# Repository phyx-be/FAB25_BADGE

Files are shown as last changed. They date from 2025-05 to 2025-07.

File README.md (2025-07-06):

# FAB25_BADGE
We've been asked by our friends over at [FabLab Leuven](https://fablab-leuven.be/) to design a solder kit for the [FAB25](https://fab25.fabevent.org/) conference in Czechia.

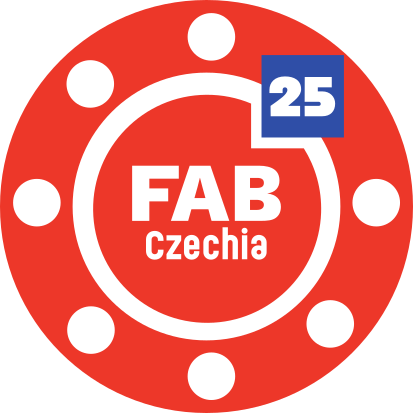
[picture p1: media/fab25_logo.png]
FAB25 logo


## Design
In order to make the kit a bit more advanced we opted to use a [555 timer](https://www.ti.com/product/TLC555) IC to generator a clock signal for a [4017 counter](https://www.ti.com/product/CD4017B) IC. This will result in LEDs lighting up one by one around the logo. A slide switch on the back allows users to disable the light show to save power. 

## Chip marking
Since the ICs would cover op parts of the identifying marks of the logo, we opted to mark the ICs with "25" and "Czechia". This was done by laser engraving the ICs and filling those engravings with paint.

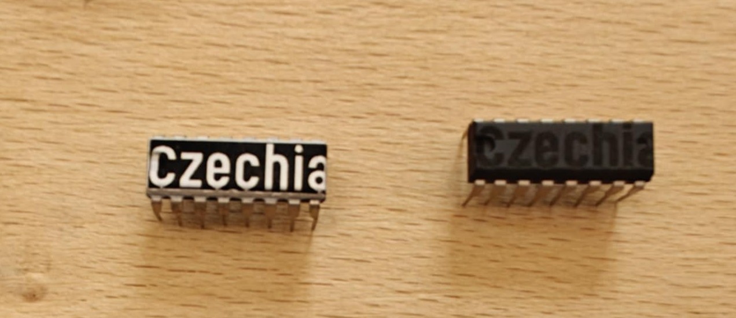
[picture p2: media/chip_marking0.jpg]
chip engraving

Sample chip engraving and painting.

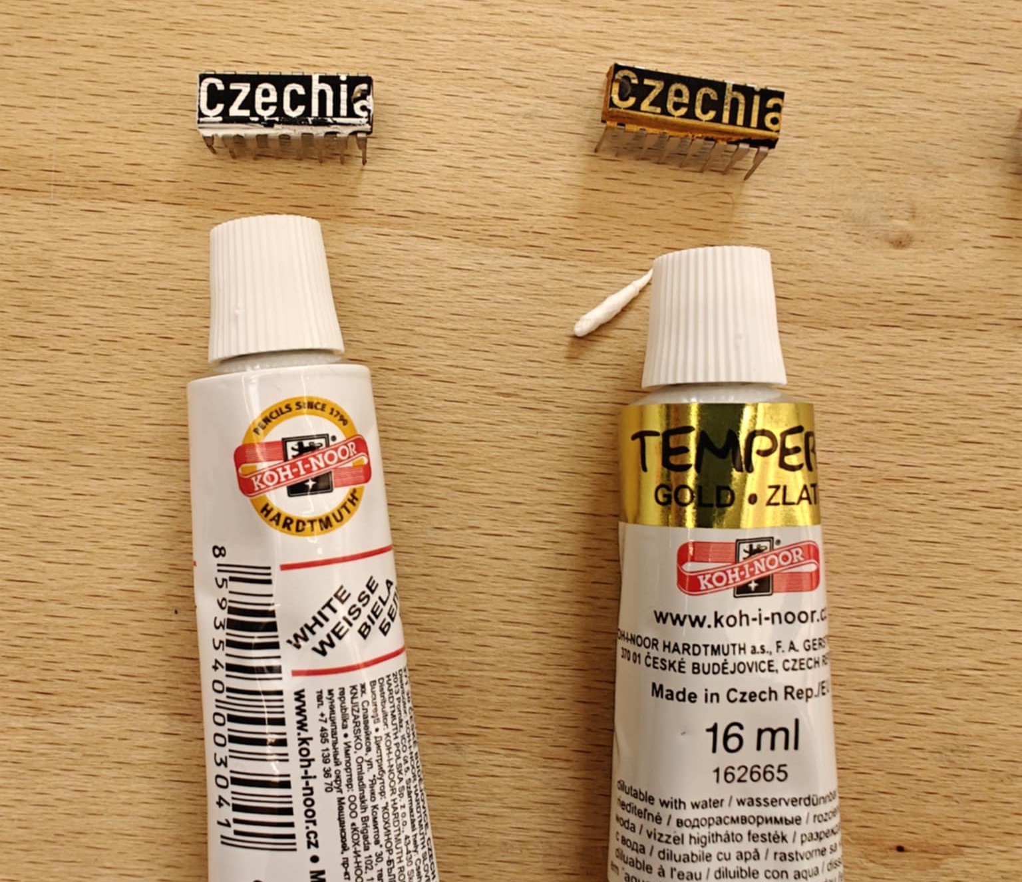
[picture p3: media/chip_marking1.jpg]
chip painting with white and gold paint

First test with gold and white paint.

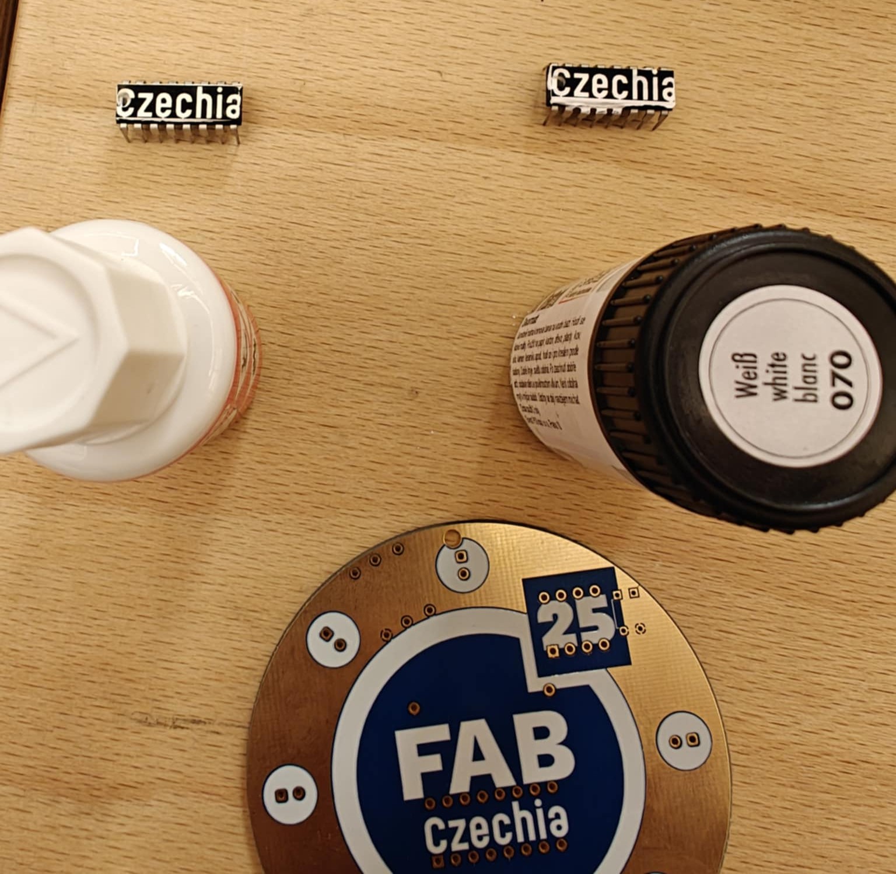
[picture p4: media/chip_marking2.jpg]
chip painting with alternative white paints

Testing with different white paints.

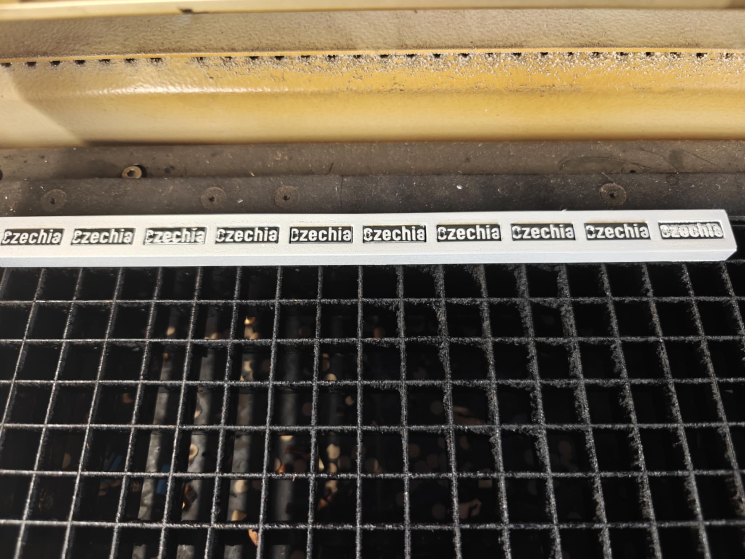
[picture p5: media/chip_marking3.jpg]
mass chip engraving and painting with a rig in a laser cutter

Mass engraving of the ICs in the laser cutter with a custom jig to speed up the process (a total of 2000 chips had to be marked).

## REV 00
Initial version of the design based on the [FAB25](https://fab25.fabevent.org/) logo.

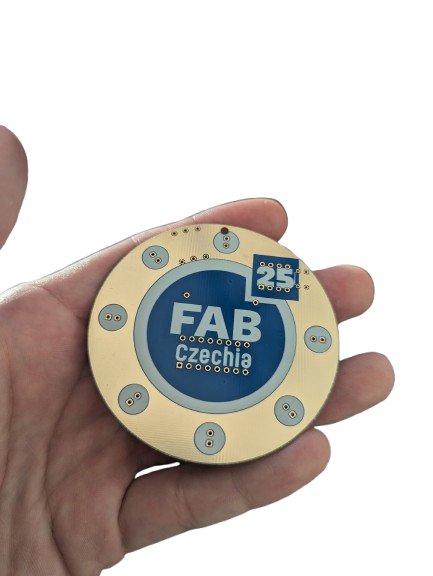
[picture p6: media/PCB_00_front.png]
Bare PCB front

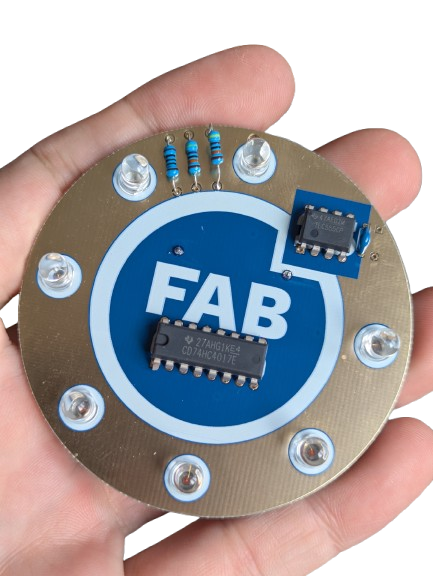
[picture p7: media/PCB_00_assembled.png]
Assembled PCB front


## REV 01
Revision 01 is the mass production version of the kit. Besides an update to the graphical design and adding the sponsor logo, we als removed the unnecessary capacitor, added the switch and increased the animation speed by reducing the 470kΩ resistors to 100kΩ. 
R1 and R2 are 100kΩ, C1 is 1µF, the animation speed can be calculated using the following formula: f=1.44/[(R1+2*R2)C1]=4,8Hz

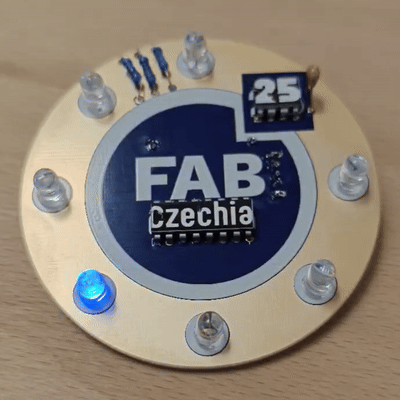
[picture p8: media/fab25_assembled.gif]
Animated FAB25 kit


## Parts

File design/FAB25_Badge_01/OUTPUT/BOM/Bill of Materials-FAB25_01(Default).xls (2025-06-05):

Bill of Materials |  |  | FAB25 Logo
Project: |  | FAB25_01.PrjPcb
Revision: |  | 01
Variant: |  | Default
Creation Date: | 04/06/2025 | 11:08
Print Date: | 2025-06-04 | 11:08:26
Footprint | Comment | LibRef | Designator | Value | Description | Supplier 1 | Supplier Part Number 1 | Supplier 2 | Supplier Part Number 2 | Supplier 3 | Supplier Part Number 3 | Quantity
BAT_CR2032_China | CR2032 Battery Holder | BAT 20mm Coin Cell Holder Generic | BAT1 | CR2032 | BAT 20mm Coin Cell Holder Generic | LCSC | C5239862 | LCSC | C70376 |  |  | 1
C_5.08mm |  | CAP 1uF 50V X7R 5.08mm | C1 | 1uF 50V X7R | CAP 1uF 50V X7R 5.08mm | LCSC | C263186 | LCSC | C5632434 |  |  | 1
LED_5MM_RD | Default 5mm Red LED | LED Red 5mm | D1, D2, D3, D4, D5, D6, D7 |  | LED Red 5mm | Farnell | 2335725 | LCSC | C2895484 |  |  | 7
RES_10mm |  | RES 100k 1/4W | R1, R2 | 100k | RES 100k 1/4W | LCSC | C2903268 | LCSC | C2843019 | Generic | 100k 1/4W 1% TH 10mm | 2
RES_10mm |  | RES 100R 1/4W | R3 | 100R | RES 100R 1/4W | LCSC | C57438 | LCSC | C2903231 | Generic | 100R 1/4W 1% TH 10mm | 1
SS-12D07 | mini Switch 1 pole double throw | SW 1P2T micro SS-12D07 | SW1 | SS-12D07 | SW 1P2T micro SS-12D07 | LCSC | C22435632 | LCSC | C22435634 | LCSC | C22435633 | 1
DIP_N_8 | General purpose Timer IC 555 3V DIP 8 | 555 Timer DIP8 3V | U1 | 555 | 555 Timer DIP8 3V | LCSC | C725329 | LCSC | C5274684 |  |  | 1
DIP_N_16 | CD74HC4017 High-Speed CMOS Logic Decade Counter/Divider with 10 Decoded Outputs | COUNT CD74HC4017E DIP16 | U2 | CD74HC4017E | COUNT CD74HC4017E DIP16 | Ti | CD74HC4017E | LCSC | C354048 | Farnell | 3119779 | 1
 |  |  |  |  |  |  |  |  |  |  |  | 15
Approved |  | Notes

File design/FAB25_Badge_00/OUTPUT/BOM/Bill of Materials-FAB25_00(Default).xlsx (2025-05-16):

Comment | Description | Designator | Footprint | LibRef | Quantity | Supplier 1 | Supplier Part Number 1 | Value | Supplier 2 | Supplier Part Number 2 | Supplier 3 | Supplier Part Number 3
CR2032 Battery Holder | BAT 20mm Coin Cell Holder Generic | BAT1 | BAT_CR2032_China | BAT 20mm Coin Cell Holder Generic | 1 | LCSC | C5239862 | CR2032 | LCSC | C70376
 | CAP 1uF 50V X7R 5.08mm | C1 | C_5.08mm | CAP 1uF 50V X7R 5.08mm | 1 | LCSC | C263186 | 1uF 50V X7R | LCSC | C5632434
Default 5mm Red LED | LED Red 5mm | D1, D2, D3, D4, D5, D6, D7 | LED_5MM_RD | LED Red 5mm | 7 | Farnell | 2335725 |  | LCSC | C2895484
 | RES 470k 1/4W | R1, R2 | RES_10mm | RES 470k 1/4W | 2 | LCSC | C119381 | 470k | LCSC | C2903284 | Generic | 470k 1/4W 1% TH 10mm
 | RES 100R 1/4W | R3 | RES_10mm | RES 100R 1/4W | 1 | LCSC | C57438 | 100R | LCSC | C2903231 | Generic | 100R 1/4W 1% TH 10mm
General purpose Timer IC 555 3V DIP 8 | 555 Timer DIP8 3V | U1 | DIP_N_8 | 555 Timer DIP8 3V | 1 | LCSC | C725329 | 555 | LCSC | C5274684
CD74HC4017 High-Speed CMOS Logic Decade Counter/Divider with 10 Decoded Outputs | COUNT CD74HC4017E DIP16 | U2 | DIP_N_16 | COUNT CD74HC4017E DIP16 | 1 | Ti | CD74HC4017E | CD74HC4017E | LCSC | C354048 | Farnell | 3119779

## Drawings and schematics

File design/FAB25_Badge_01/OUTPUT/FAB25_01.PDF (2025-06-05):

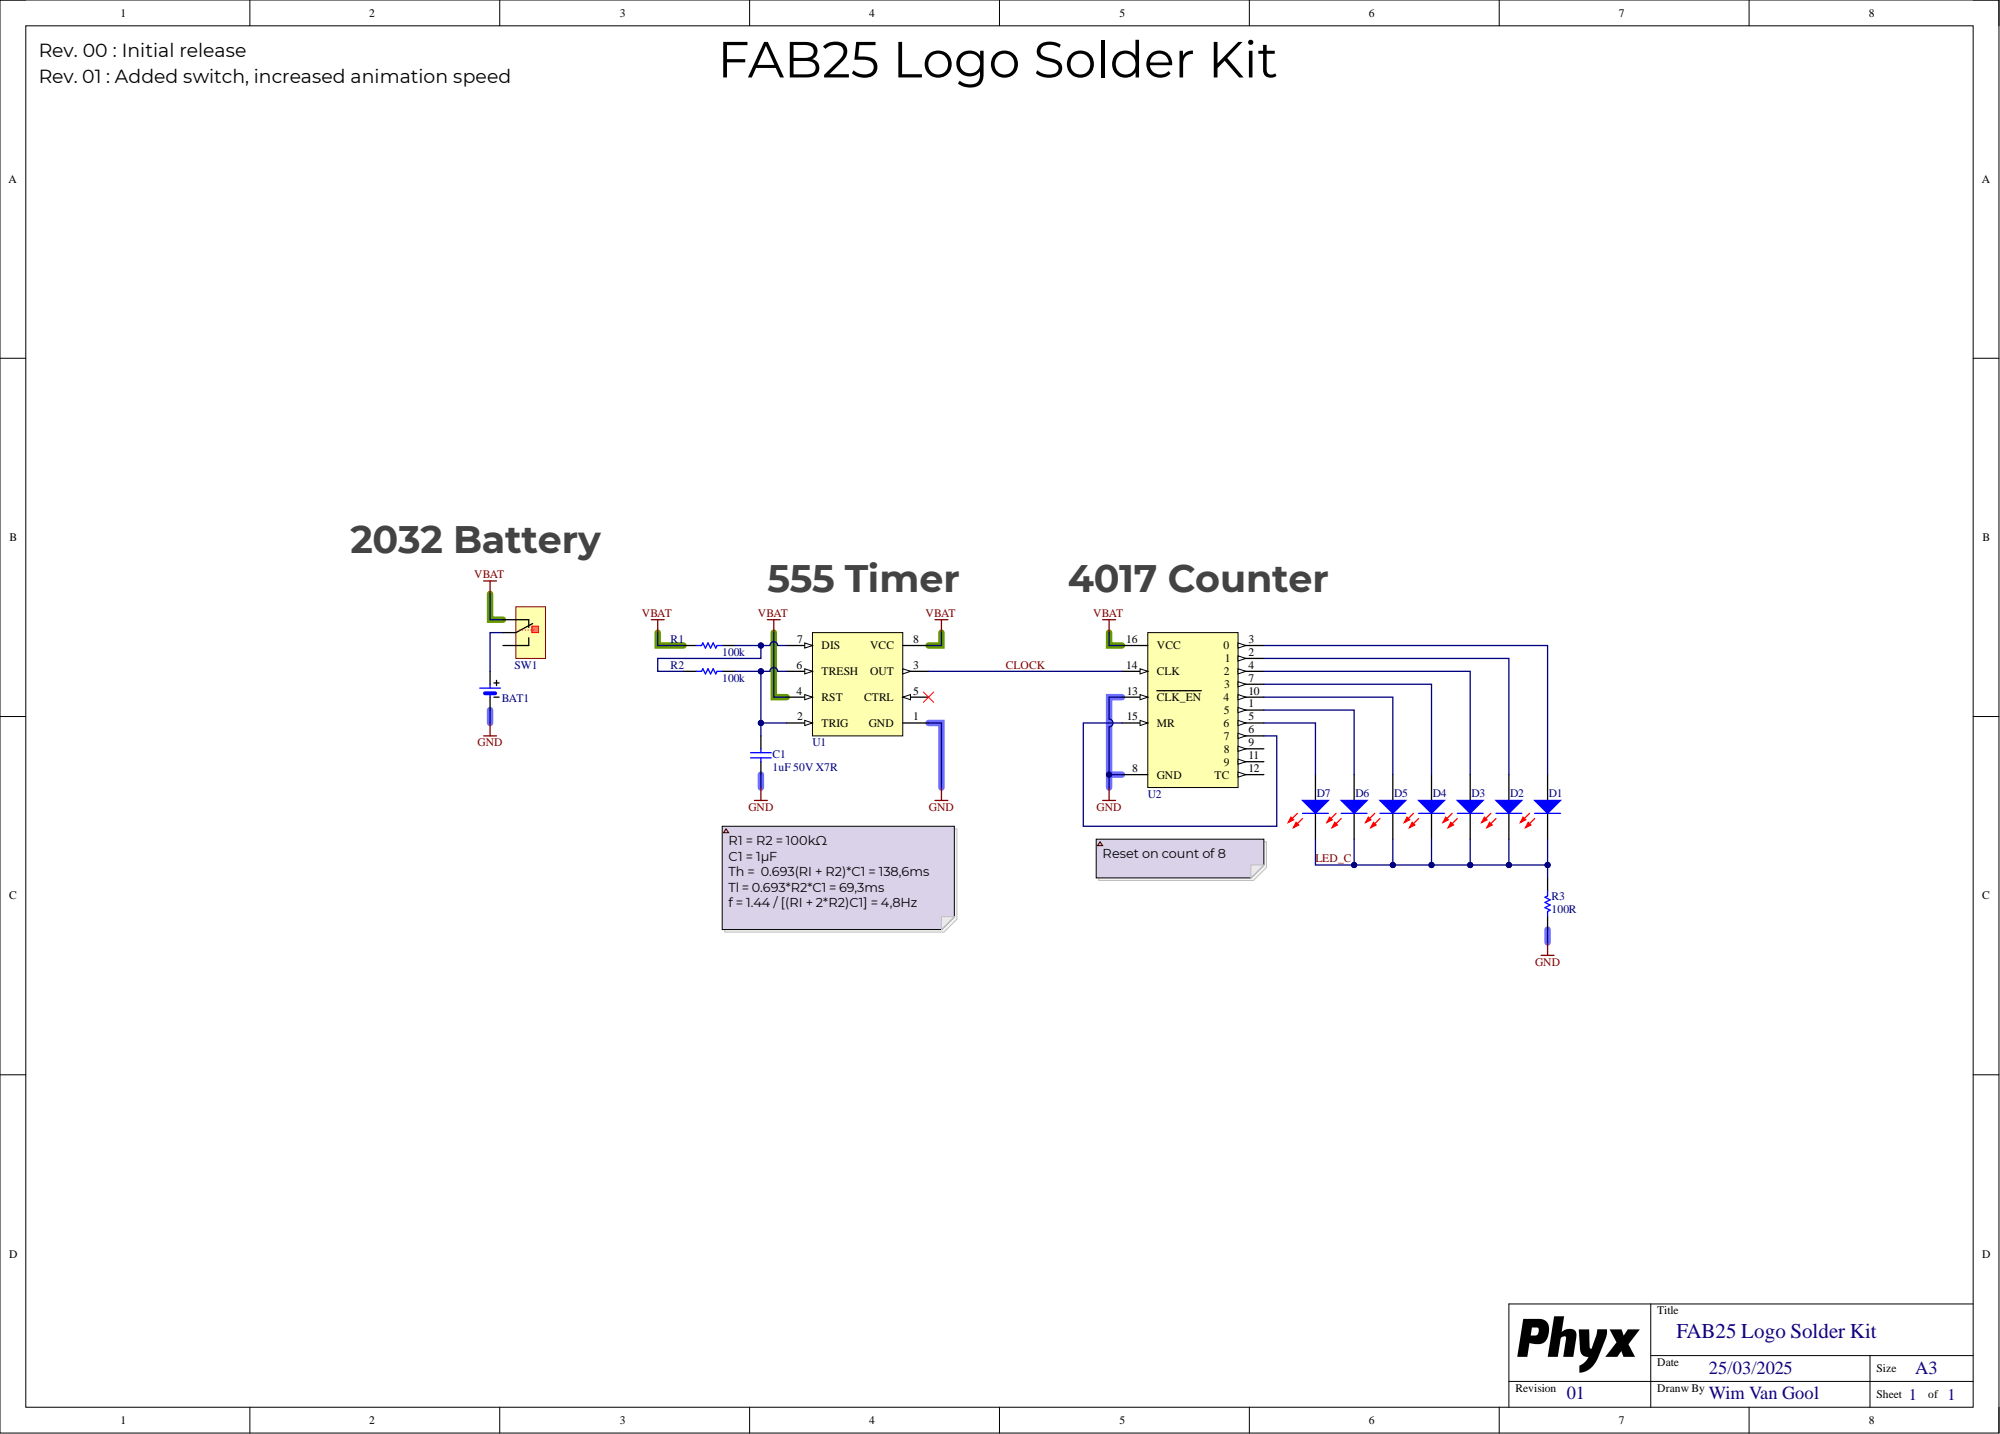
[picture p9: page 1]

FAB25 Logo Solder Kit Rev. 00 : Initial release
Rev. 01 :

Reset on count of

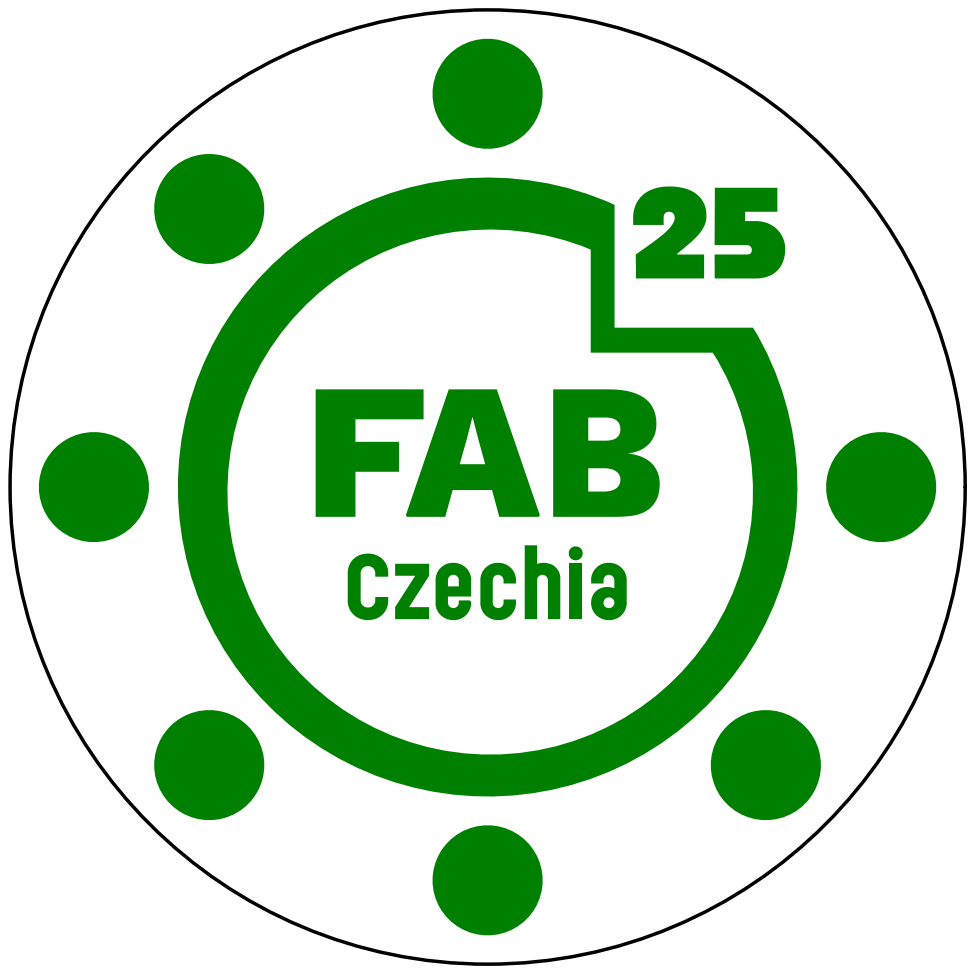
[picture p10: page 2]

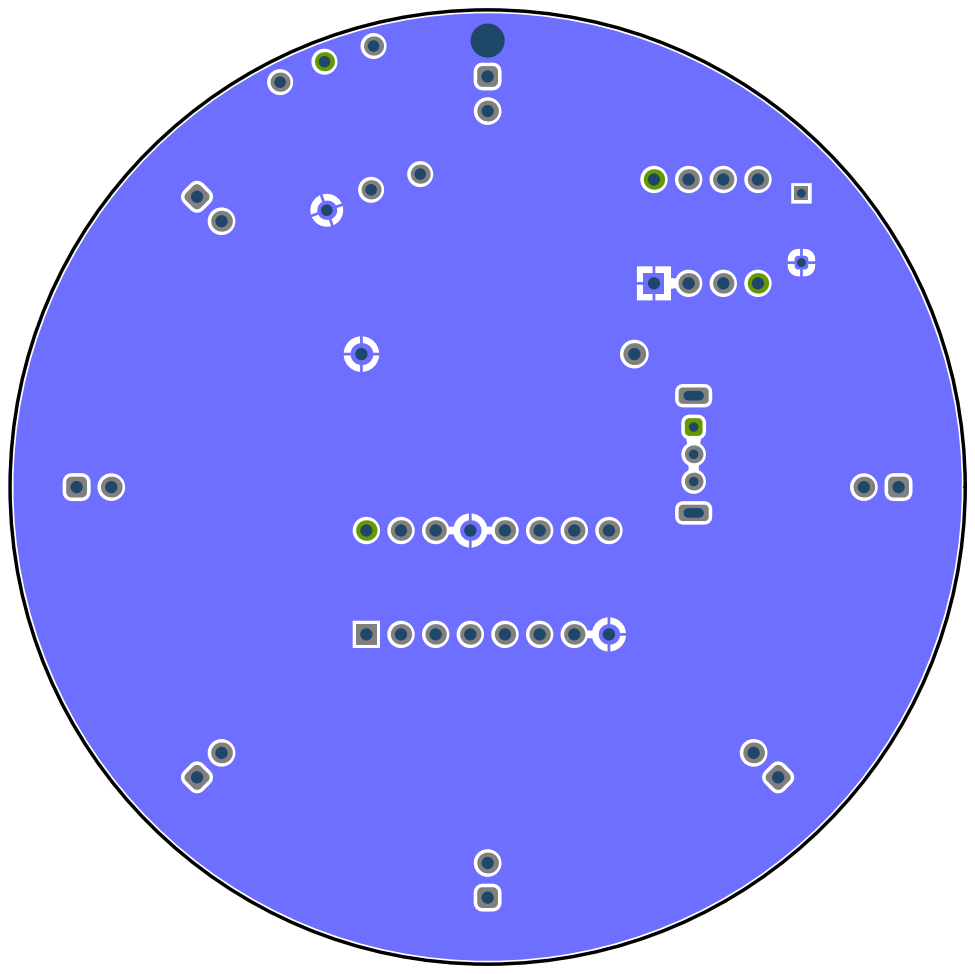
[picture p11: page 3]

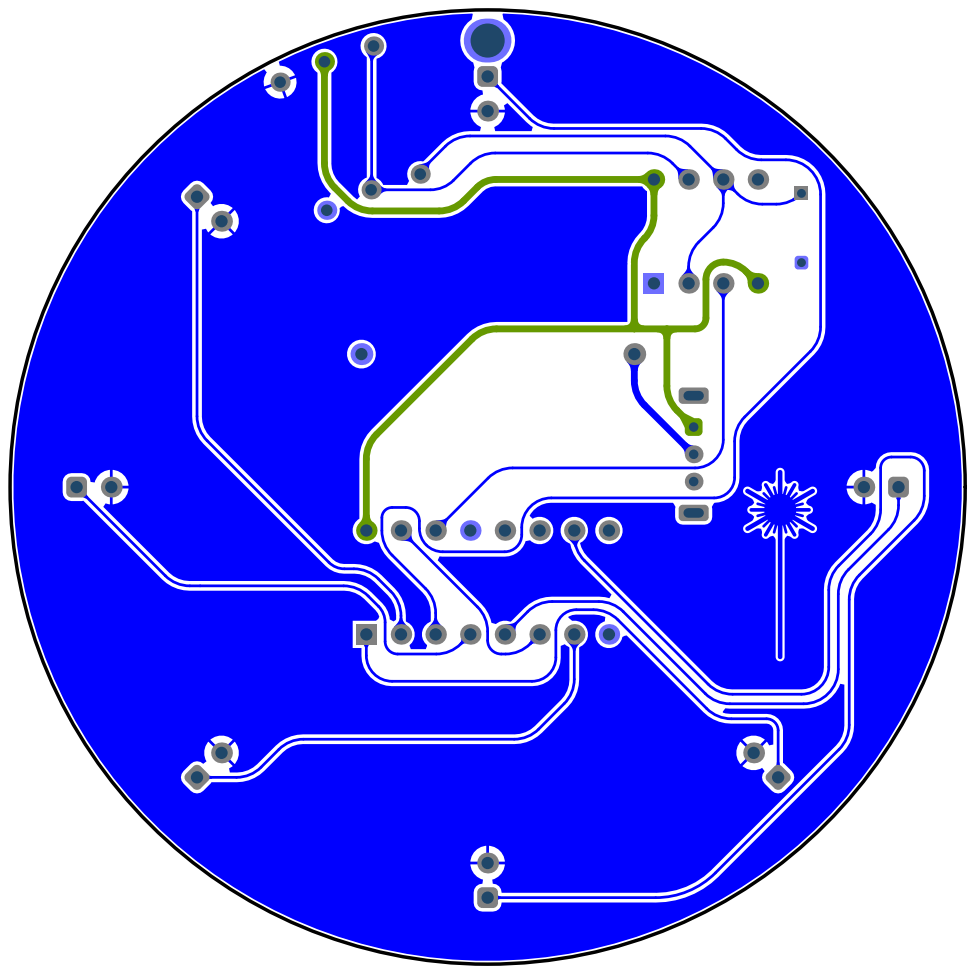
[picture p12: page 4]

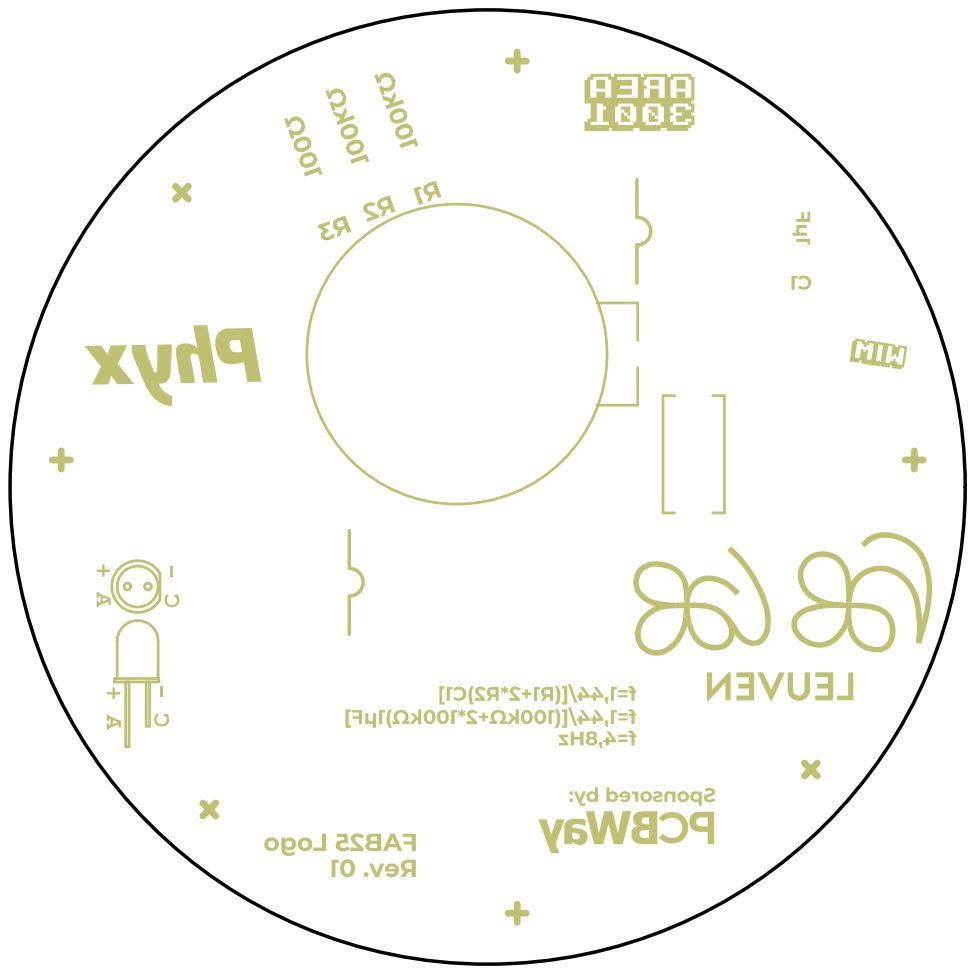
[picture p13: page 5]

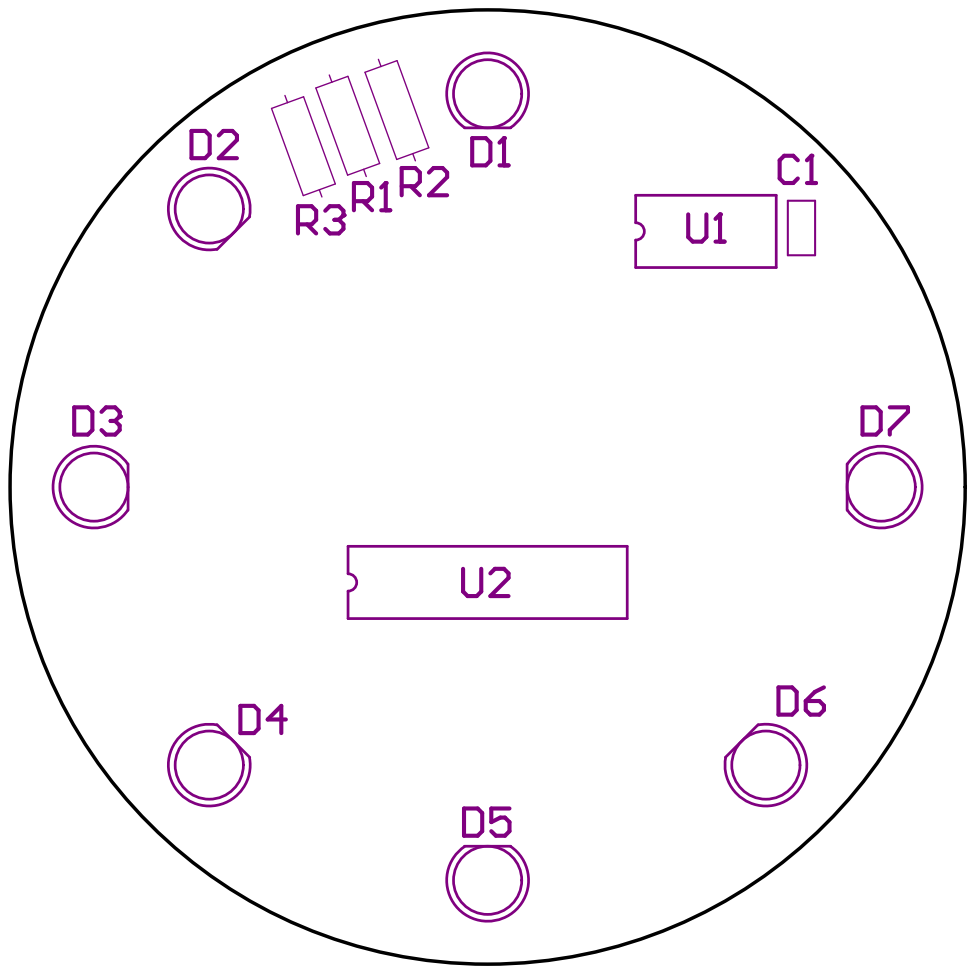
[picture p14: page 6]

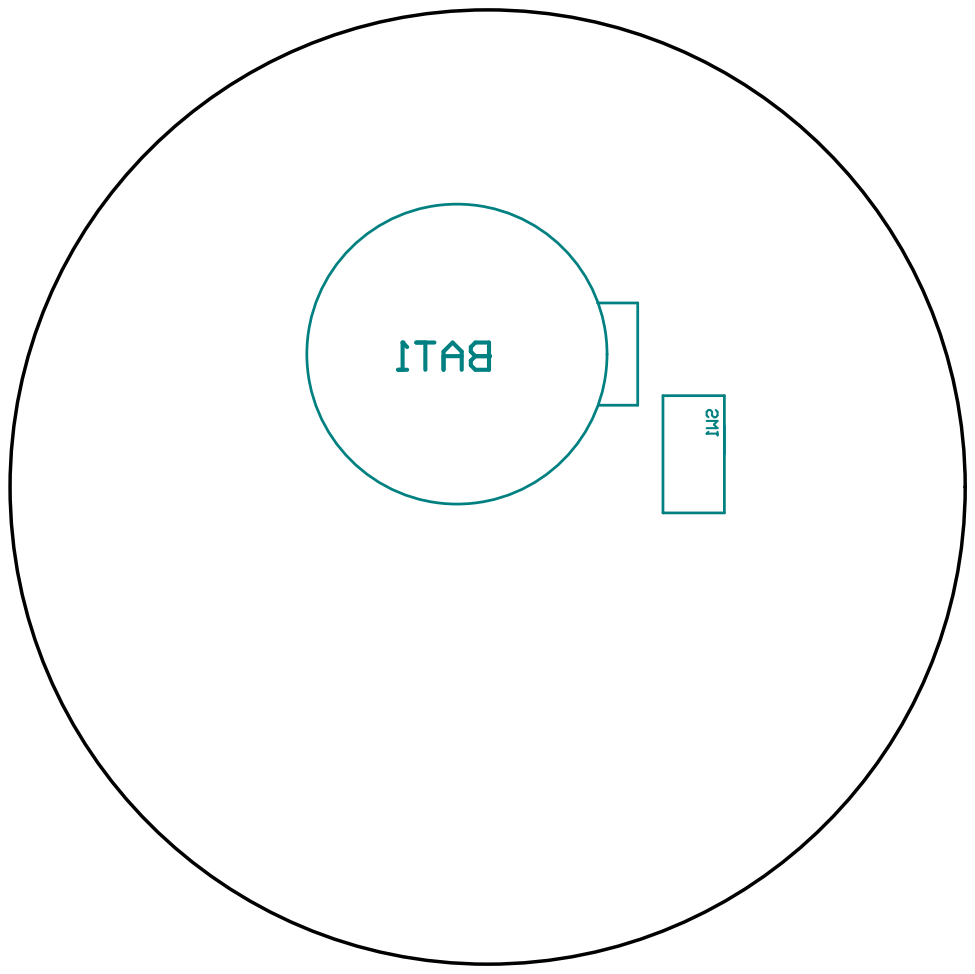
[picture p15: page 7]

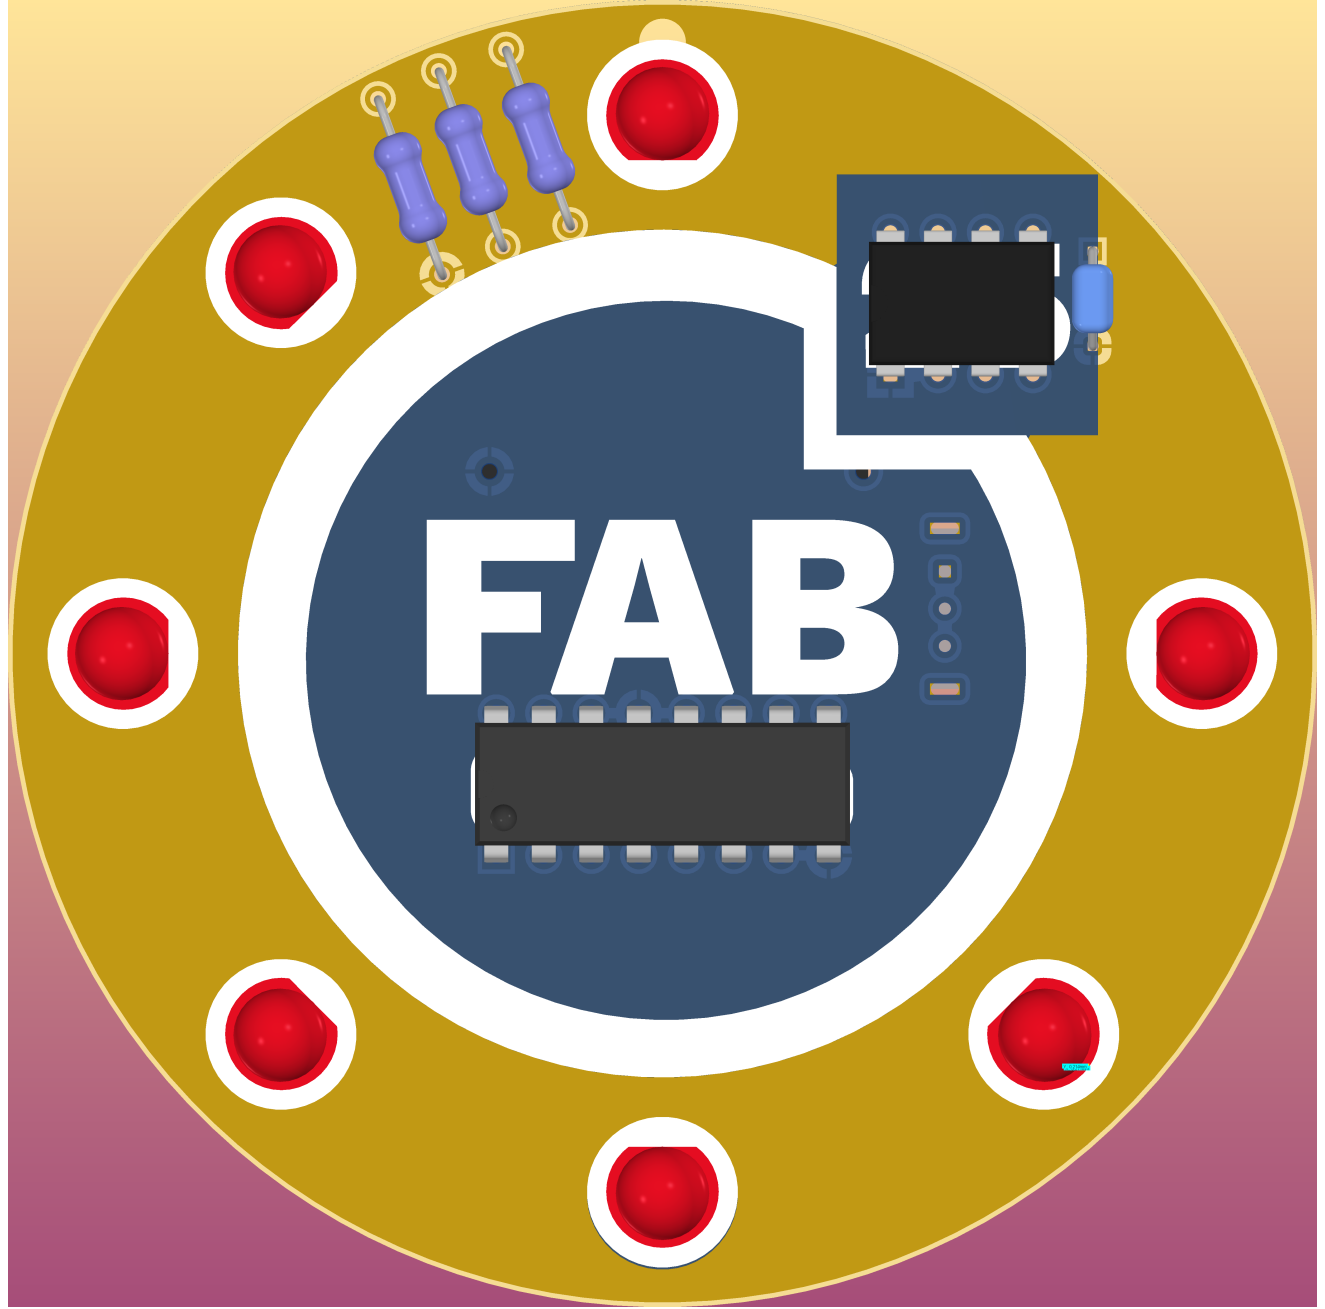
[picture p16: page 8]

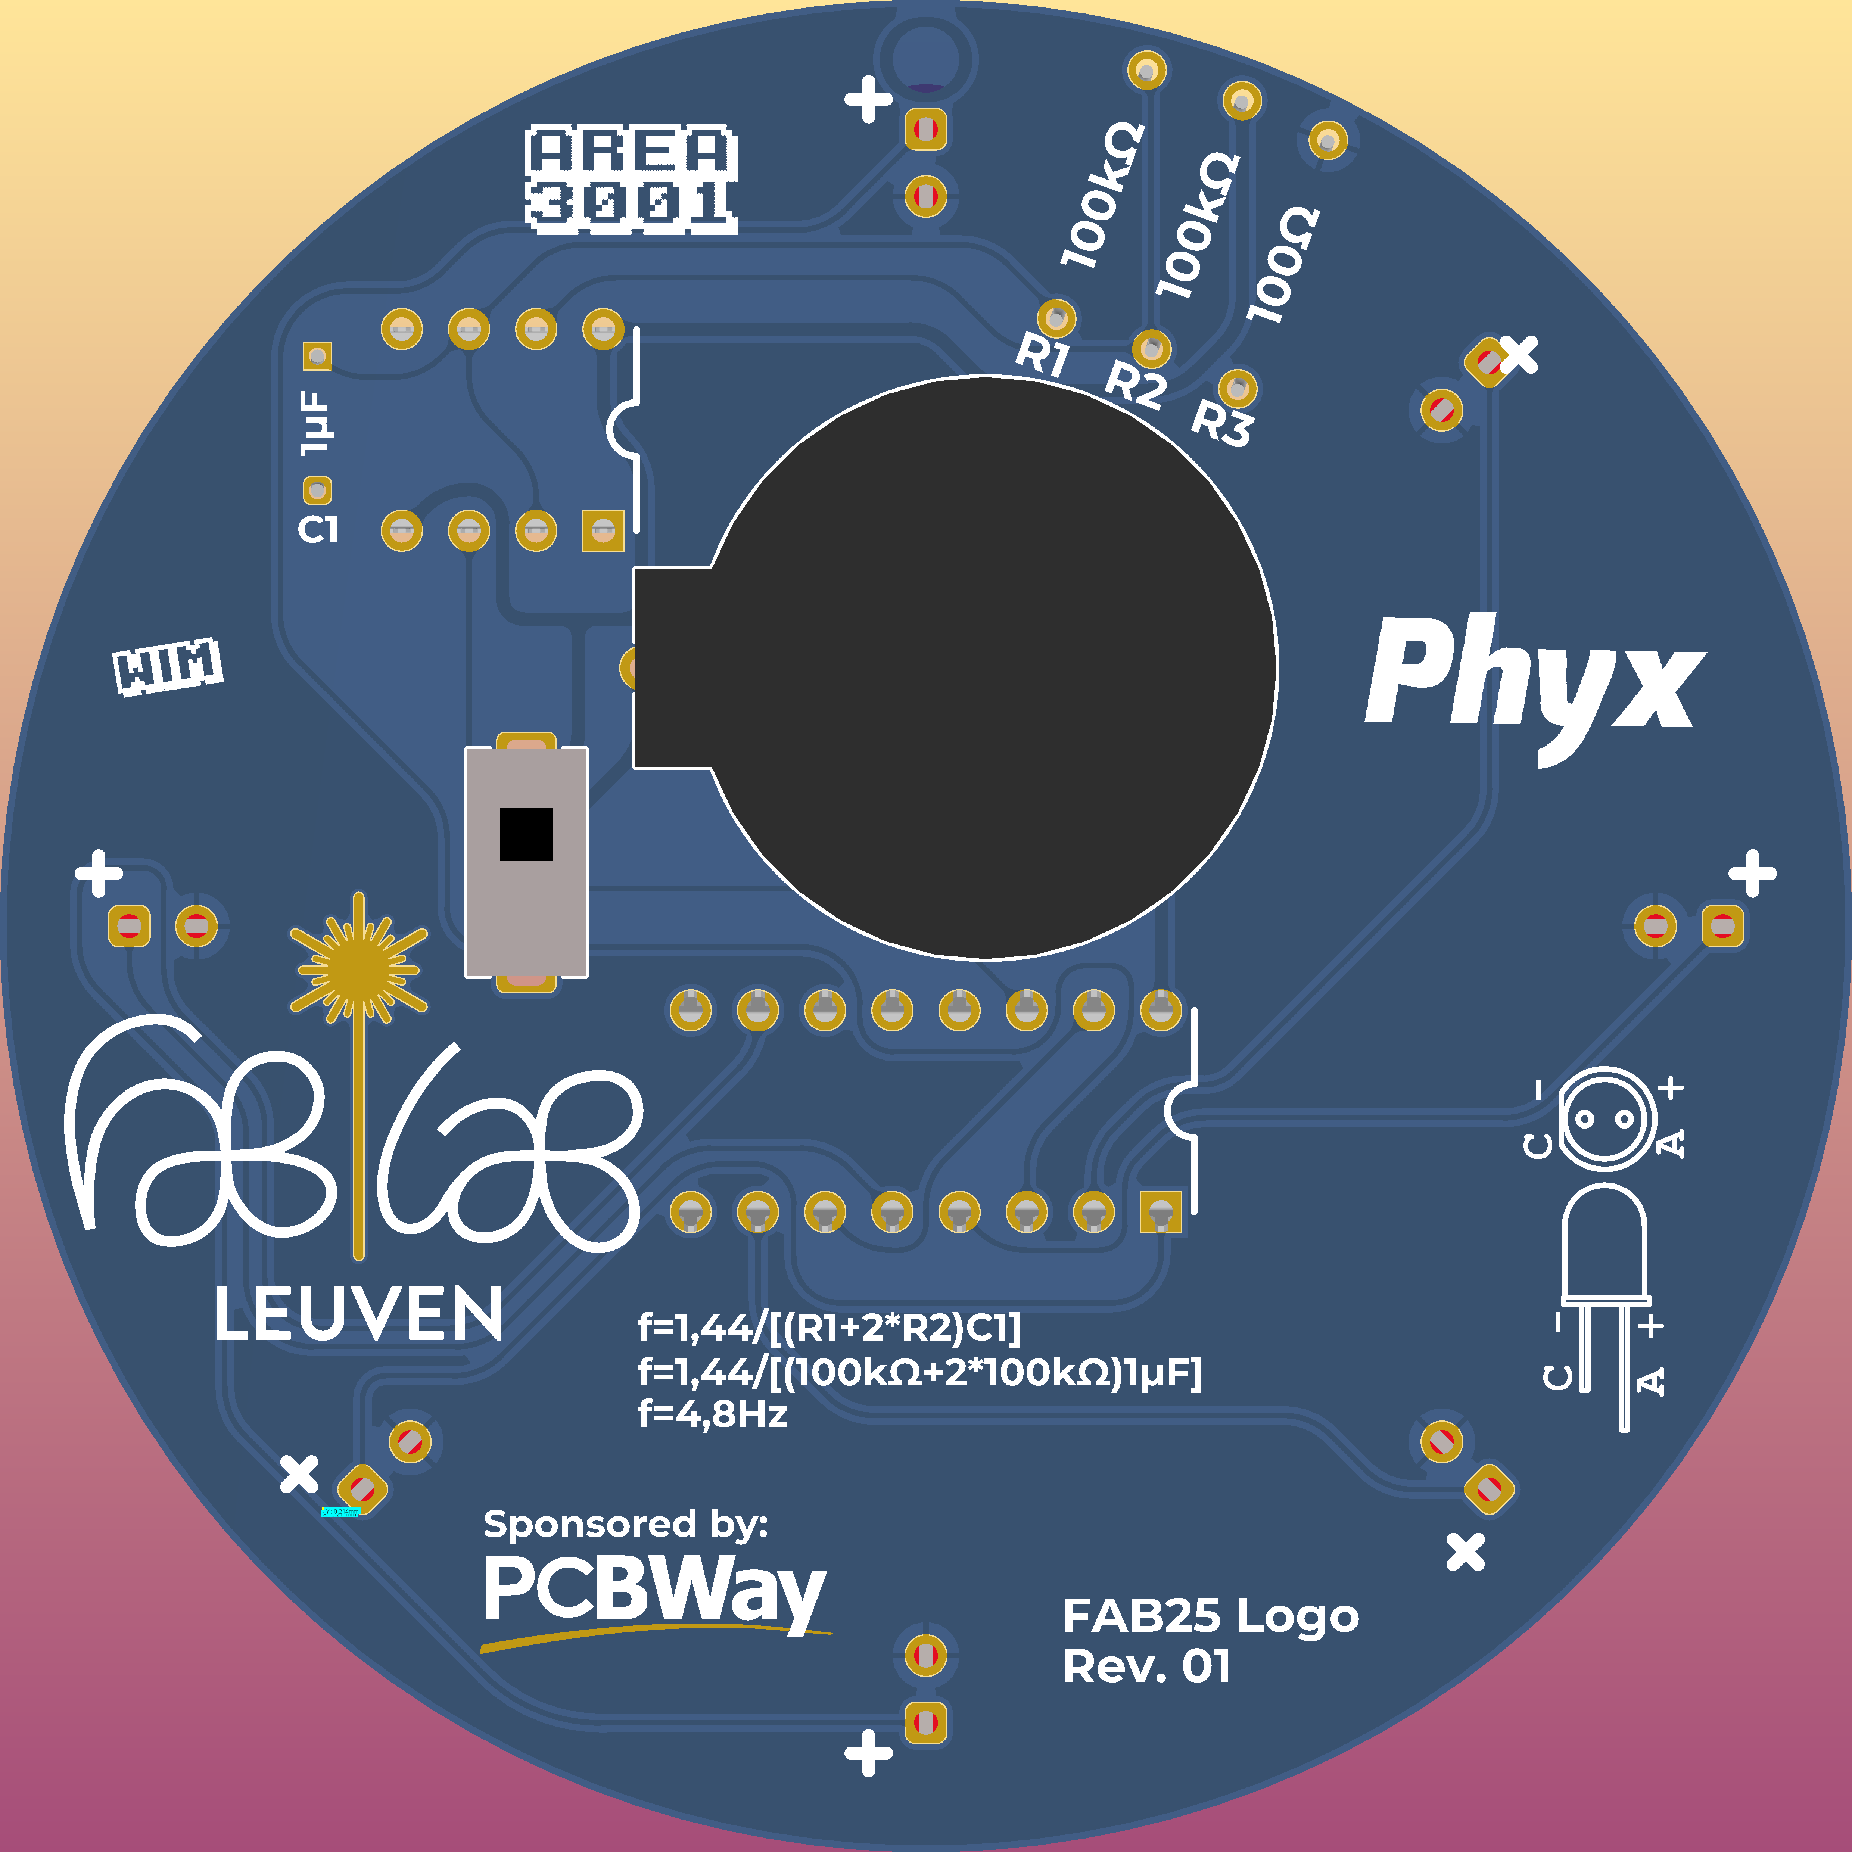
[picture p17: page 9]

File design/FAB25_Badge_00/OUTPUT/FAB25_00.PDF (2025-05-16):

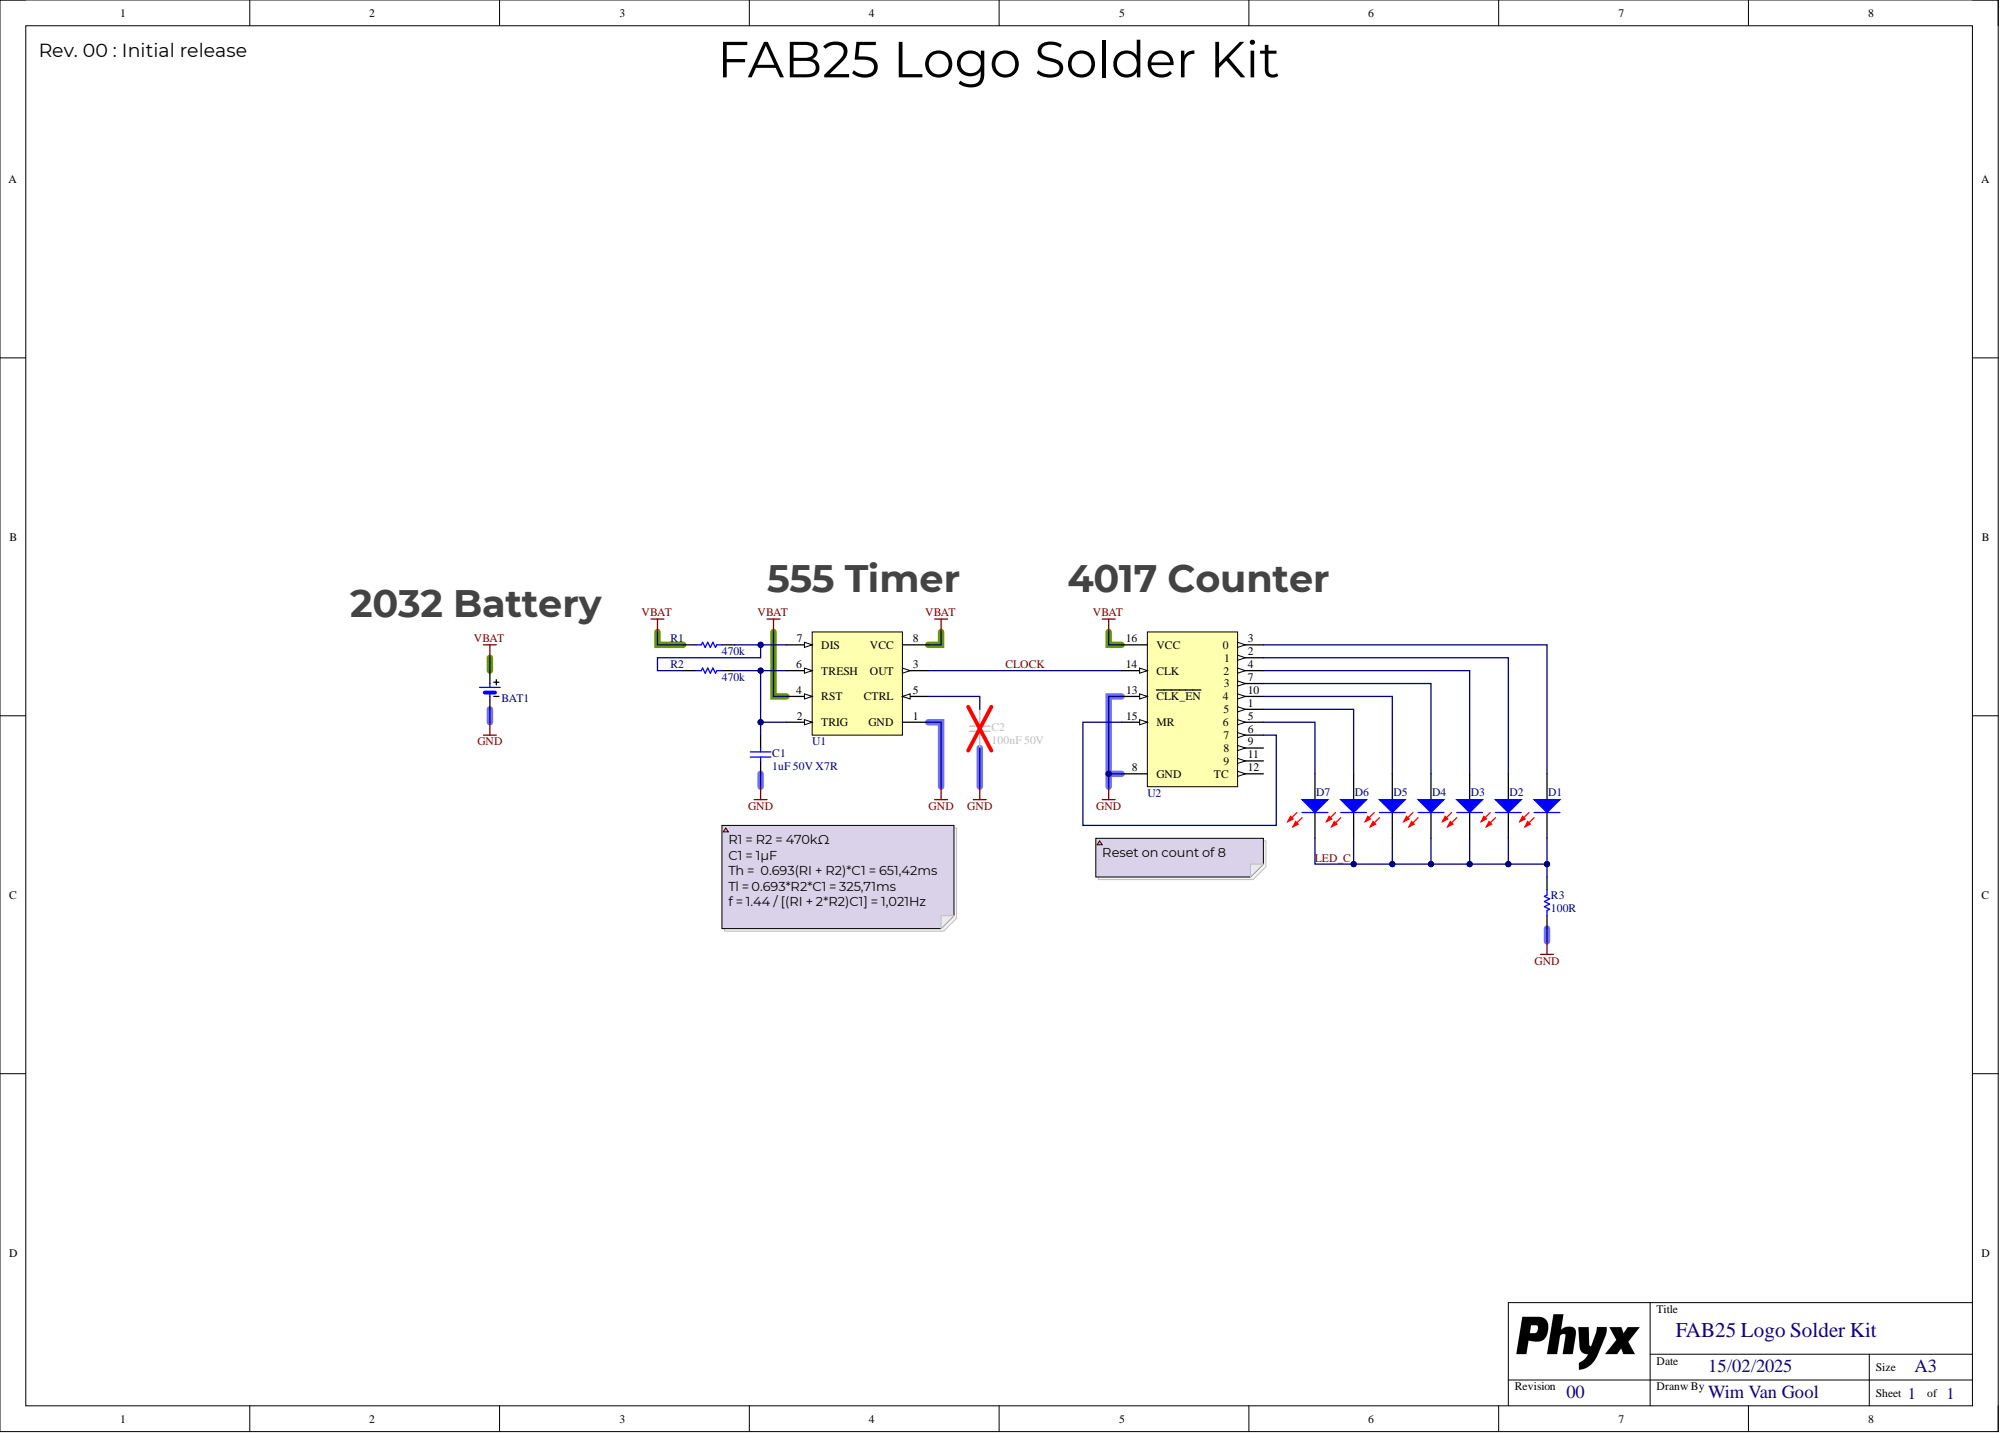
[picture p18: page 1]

FAB25 Logo Solder Kit Rev. 00 : Initial release

Reset on count of

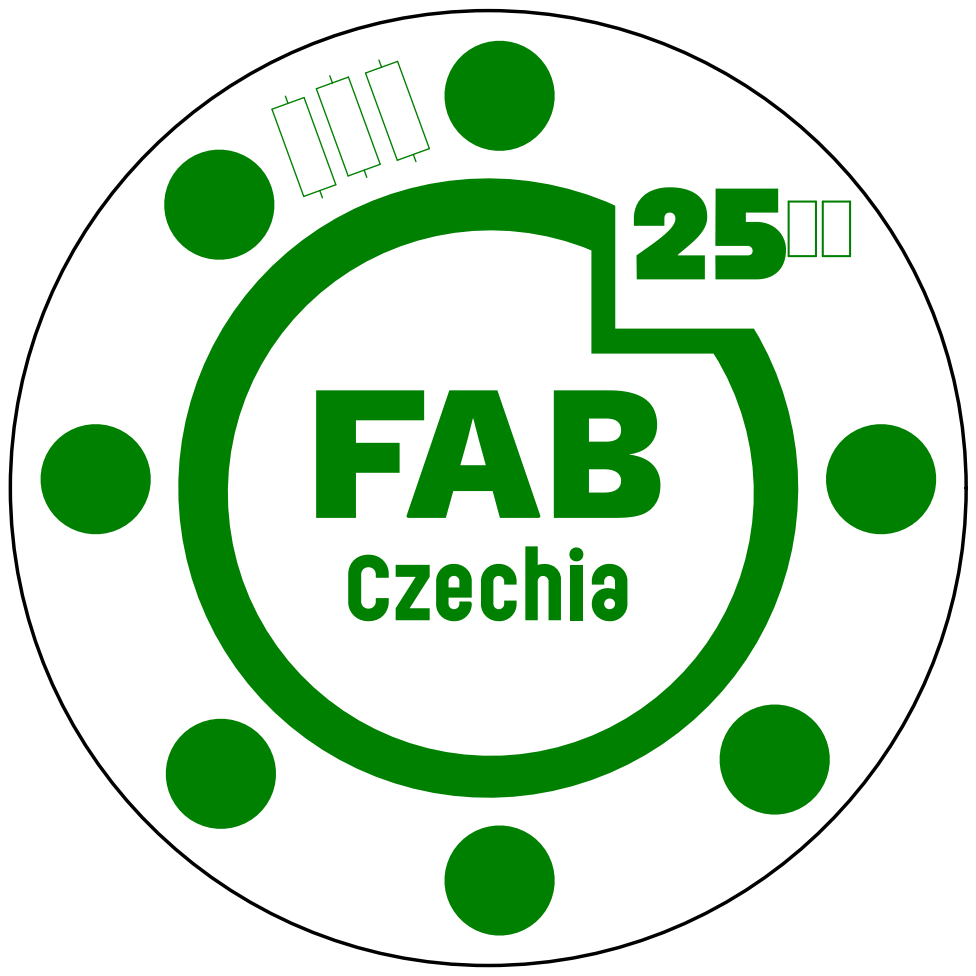
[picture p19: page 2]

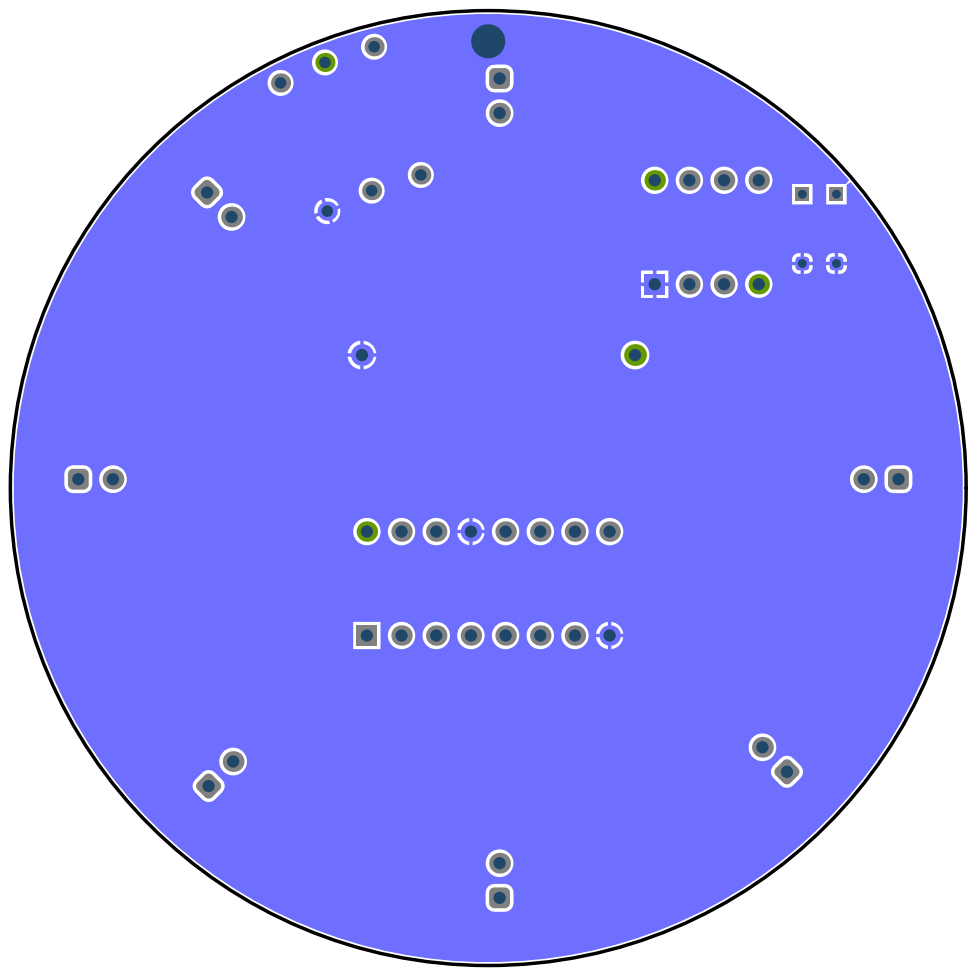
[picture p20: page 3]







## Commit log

2025-05-16 initial commit
    added REV 00 design files
    [Bill of Materials-FAB25_00(Default).xlsx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]
2025-05-16 REV 01 added
    Added the design files for revision 01
    [Bill of Materials-FAB25_01(Default).xls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]
2025-06-05 modified graphical design of badge
    new version of the badge graphics, added sponsor logo
    [Bill of Materials-FAB25_01(Default).xls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]
